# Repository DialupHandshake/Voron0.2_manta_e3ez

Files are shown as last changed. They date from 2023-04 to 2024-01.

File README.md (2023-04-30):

# Voron0.2_manta_e3ez
Configuration for Voron 0.2 printer with Bigtreetech Manta E3EZ board and CB1.
If you just need a config with pin mapping for Voron 0, grab btt_manta_e3ez_voron0_generic.cfg and rename it to printer.cfg. 
Otherwise feel free to use my printer.cfg.
If you are using CAN bus, there is a config for that in the CAN_bus_config folder.

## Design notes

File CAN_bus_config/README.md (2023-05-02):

This is a config with Manta E3EZ and BTT EBB36 communicating on CAN network, without KAMP (Klipper Adaptive Meshing and Purging) installed.

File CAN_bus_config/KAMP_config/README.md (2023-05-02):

This is a config with Manta E3EZ with EBB36 communicating over CAN, with KAMP (Klipper Adaptive Meshing and Purging) installed but used only for purging.

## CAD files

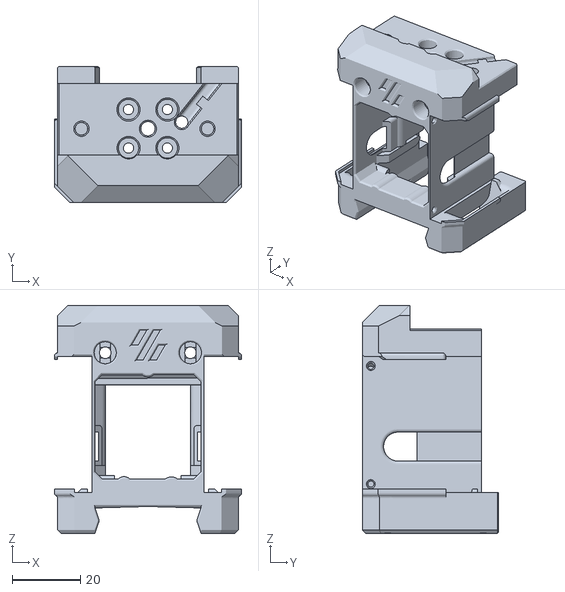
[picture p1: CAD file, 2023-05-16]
dragonburner.stl
55.0 x 40.0 x 66.9

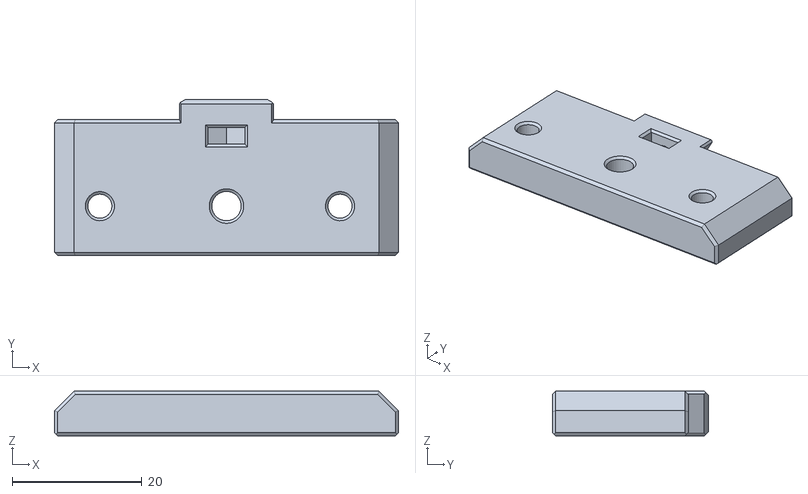
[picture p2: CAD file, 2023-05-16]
Orbiter_mount.stl
53.0 x 24.1 x 6.90

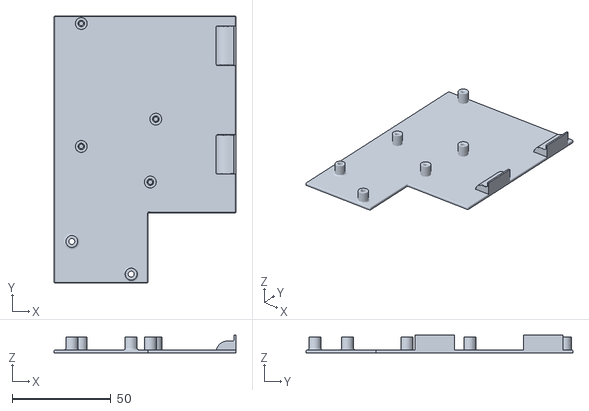
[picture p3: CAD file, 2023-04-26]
Board_tray_buck.stl
92.0 x 135.0 x 9.00

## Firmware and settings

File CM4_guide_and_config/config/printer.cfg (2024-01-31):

# This file contains common pin mappings for the BIGTREETECH Manta E3EZ and BIGTREETECH EBB36 v1.2 running on CAN network.
# To use this config, compile the firmware with the following options:
# Micro-controller Architecture (STMicroelectronics STM32) -- borth boards
# Processor model (STM32G0B1) -- borth boards (EBB36 v1.1 and 1.2 use STM32G0B1, and EBB36 v1.0 uses STM32F072. More details here: https://github.com/maz0r/klipper_canbus/blob/main/index.md)
# Clock Reference (8 MHz crystal) -- both boards
# Application start offset (8KiB offset) -- both boards
# (1000000) CAN bus speed -- both boards
# When building for Manta E3EZ, select "USB to CAN bus bridge on PA11/PA12" and "CAN bus (on PB12/PB13)"
# When building for EBB36 v1.2, select "CAN bus (on PB0/PB1)"



[include mainsail.cfg]
[include KAMP_Settings.cfg]
[include pid_macro.cfg]

# Enable object exclusion
[exclude_object]

[force_move]
enable_force_move: True

[respond]

[skew_correction]

# Enable arcs support
[gcode_arcs]
resolution: 0.1

[virtual_sdcard]
path: ~/printer_data/gcodes
on_error_gcode: CANCEL_PRINT

[mcu]
canbus_uuid=2cca93642053

[mcu can0]
canbus_uuid=84c9eddddf6b							# Run the following command to locate the uuid >   ~/klippy-env/bin/python ~/klipper/scripts/canbus_query.py can0

#####################################################################
#     	Printer definition
#####################################################################

[printer]
kinematics: corexy
max_velocity: 300
max_accel: 2000
max_z_velocity: 15
max_z_accel: 45
square_corner_velocity: 6.0

#####################################################################
#     	 X/Y Stepper Settings
#####################################################################

[stepper_x]
step_pin: PA14
dir_pin: PA10
enable_pin: !PA13
microsteps: 32
#full_steps_per_rotation: 200
rotation_distance: 40
endstop_pin: tmc2209_stepper_x:virtual_endstop
position_endstop: 120
position_max: 120
homing_speed: 40								 	# For sensorless homing it is recommended not to go above 40mm/s  
homing_retract_dist: 0

[tmc2209 stepper_x]
uart_pin: PB8
diag_pin: PC4										# Sensorless homing won't work if this pin is not jumped
interpolate: False									
run_current: 0.5
sense_resistor: 0.110
stealthchop_threshold: 0						# Set to 999999 to turn stealthchop on, and 0 to use spreadcycle
driver_SGTHRS: 60          							# Sensitivity for sensorless homing, max sensitivity is 255

[stepper_y]
step_pin: PC8
dir_pin: PA15
enable_pin: !PC14
microsteps: 32
rotation_distance: 40
endstop_pin: tmc2209_stepper_y:virtual_endstop
position_endstop: 120
position_max: 120
homing_speed: 40
homing_retract_dist: 0

[tmc2209 stepper_y]
uart_pin: PC9
diag_pin: PB0										# Sensorless homing won't work if this pin is not jumped
interpolate: False									
run_current: 0.5
sense_resistor: 0.110
stealthchop_threshold: 0					# Set to 999999 to turn stealthchop on, and 0 to use spreadcycle
driver_SGTHRS: 100            						# Sensitivity for sensorless homing, max sensitivity is 255

#####################################################################
#   Z Stepper Settings
#####################################################################

[stepper_z]
step_pin: PD2
dir_pin: PD4
enable_pin: !PD3
microsteps: 32
rotation_distance: 8
endstop_pin: probe:z_virtual_endstop
#position_endstop: 120
position_max: 120
position_min: -6
homing_speed: 20
second_homing_speed: 3.0
homing_retract_dist: 3.0

[tmc2209 stepper_z]
uart_pin: PD0
#diag_pin: PC6
interpolate: False
run_current: 0.3				
sense_resistor: 0.110
stealthchop_threshold: 0

#####################################################################
#   Extruder
#####################################################################

[extruder]
step_pin: can0:EXT_STEP
dir_pin: can0:EXT_DIR
enable_pin: !can0:EXT_EN
rotation_distance: 35.486
gear_ratio: 75:10 										#For Orbiter 2.0
microsteps: 16
full_steps_per_rotation: 200 							#1.8deg Motor
max_extrude_only_distance: 500
max_extrude_only_velocity: 120
max_extrude_only_accel: 1500
max_extrude_cross_section: 5
nozzle_diameter: 0.400
filament_diameter: 1.750
heater_pin: can0:HE0
sensor_pin: can0:TH0
sensor_type: EPCOS 100K B57560G104F  
#control: pid
min_temp: 0
max_temp: 300
min_extrude_temp: 170
#pid_Kp: 21.527
#pid_Ki: 1.063
#pid_Kd: 108.982

[tmc2209 extruder]
uart_pin: can0:EXT_UART
interpolate: True
stealthchop_threshold: 0
run_current: 0.5
sense_resistor: 0.110
driver_TBL: 0
driver_HEND: 6
driver_HSTRT: 7
driver_TOFF: 4

#####################################################################
#   Bed Heater
#####################################################################

[heater_bed]
heater_pin: PB2 #HB
sensor_type: EPCOS 100K B57560G104F 					#Generic 3950
sensor_pin: PA3 #TB
smooth_time: 3.0
#max_power: 0.6                           				# Only needed for 100w pads
min_temp: 0
max_temp: 120
#control: pid                                        	# Do PID calibration after initial checks
#pid_kp: 68.453
#pid_ki: 2.749
#pid_kd: 426.122

#####################################################################
#   Bed Leveling
#####################################################################

[bed_mesh]
speed: 200
horizontal_move_z: 25
mesh_min: 25,25
mesh_max: 95, 95
zero_reference_position: 60, 60
probe_count: 3,3
algorithm: bicubic

[probe]
pin: can0:PROBE_2
x_offset: 20
y_offset: 0
#z_offset: 10
speed: 20.0
samples: 2
sample_retract_dist: 5.0
lift_speed: 30.0
samples_tolerance: 0.01
samples_tolerance_retries: 15
deactivate_on_each_sample: 0

[homing_override]
axes: z
gcode:
    SET_KINEMATIC_POSITION Z=0
    G1 Z5
    G28 X Y
    Query_Probe
    SS_CONDITIONAL_TAKE_PROBE
    G1 X40 Y110
    G28 Z
    G91
    G1 Z1
    G90
    SS_STOW_PROBE
	
[servo probeServo]
pin: PA7
minimum_pulse_width: 0.000544


#############################################################################################################################################
#   Firmware retraction -- uncomment this section and enable firmware retraction in slicer to use firmware retraction
#############################################################################################################################################

[firmware_retraction]
retract_length: 1.2
#   The length of filament (in mm) to retract when G10 is activated,
#   and to unretract when G11 is activated (but see
#   unretract_extra_length below). The default is 0 mm.
retract_speed: 120
#   The speed of retraction, in mm/s. The default is 20 mm/s.
unretract_extra_length: 0
#   The length (in mm) of *additional* filament to add when
#   unretracting.
unretract_speed: 90
#   The speed of unretraction, in mm/s. The default is 10 mm/s.

#####################################################################
#     	Temperature Sensors
#####################################################################

[temperature_sensor MCU]
sensor_type: temperature_mcu
min_temp: 0
max_temp: 100

[temperature_sensor CM4 Host]
sensor_type: temperature_host
min_temp: 10
max_temp: 100

[temperature_sensor EBB36 CAN Board]
sensor_type: temperature_mcu
sensor_mcu: can0

[temperature_sensor Chamber]
sensor_type: Generic 3950 
sensor_pin: PA4
min_temp: 0
max_temp: 100

## PT100 for EBB boards with MAX31865 chip
# [temperature_sensor PT100]
# sensor_type: MAX31865
# sensor_pin: can0:PT100_CS
# spi_bus: spi1
# min_temp: -50
# max_temp: 350
# rtd_reference_r: 430

#####################################################################
#   Fans
#####################################################################

# Hot End fan
[heater_fan hotend_fan]
pin: can0:FAN1
max_power: 1.0
kick_start_time: 0.5
heater: extruder
heater_temp: 50.0

# Part Cooling fan
[fan]
pin: can0:FAN0
kick_start_time: 0.25
cycle_time: 0.15
off_below: 0.10

# Mainboard fan
[heater_fan controller_fan]
pin: PB14

#####################################################################
#   Board Pins
#####################################################################

[board_pins]
aliases:
    # EXP1 header
    EXP1_1=PC1, EXP1_3=PC3, EXP1_5=PC0, EXP1_7=PA2, EXP1_9=<GND>,
    EXP1_2=PC2,  EXP1_4=<RST>, EXP1_6=PA0, EXP1_8=PA1, EXP1_10=<5V>
	
[board_pins EBB36_G0B1_v1.2] 
mcu: can0
aliases:
aliases_step:
    EXT_EN=PD2,EXT_STEP=PD0,EXT_DIR=PD1,EXT_UART=PA15
aliases_limitsw: # these are preferred for endstops (including klicky)
    LIMIT_1=PB7,LIMIT_2=PB5,LIMIT_3=PB6
aliases_bltouch: # these are the dupont connectors for bltouch
    PROBE_1=PB9,PROBE_2=PB8
aliases_fans:
    FAN0=PA0,FAN1=PA1
aliases_thermistors:
    TH0=PA3,PT100_CS=PA4,PT100_SCLK=PA5,PT100_MISO=PA6,PT100_MOSI=PA7
aliases_heaters:
    HE0=PB13
aliases_rgb:
    RGBLED=PD3
aliases_adxl:
    ADXL_CS=PB12,ADXL_SCLK=PB10,ADXL_MISO=PB2,ADXL_MOSI=PB11
aliases_i2c:
    AUX0=PB3,AUX1=PB4

#[output_pin PS_ON]
#pin: PA9

#[output_pin pb9_pin]
#pin: PB9

#[neopixel my_neopixel]
#pin: PC7
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

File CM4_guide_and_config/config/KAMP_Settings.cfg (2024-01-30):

# Below you can include specific configuration files depending on what you want KAMP to do:

# [include ./KAMP/Adaptive_Meshing.cfg]       # Include to enable adaptive meshing configuration.
[include ./KAMP/Line_Purge.cfg]             # Include to enable adaptive line purging configuration.
# [include ./KAMP/Voron_Purge.cfg]            # Include to enable adaptive Voron logo purging configuration.
[include ./KAMP/Smart_Park.cfg]             # Include to enable the Smart Park function, which parks the printhead near the print area for final heating.

[gcode_macro _KAMP_Settings]
description: This macro contains all adjustable settings for KAMP 

# The following variables are settings for KAMP as a whole.
variable_verbose_enable: True               # Set to True to enable KAMP information output when running. This is useful for debugging.

# The following variables are for adjusting adaptive mesh settings for KAMP.
variable_mesh_margin: 0                     # Expands the mesh size in millimeters if desired. Leave at 0 to disable.
variable_fuzz_amount: 0                     # Slightly randomizes mesh points to spread out wear from nozzle-based probes. Leave at 0 to disable.

# The following variables are for those with a dockable probe like Klicky, Euclid, etc.                 # ----------------  Attach Macro | Detach Macro
variable_probe_dock_enable: True           # Set to True to enable the usage of a dockable probe.      # ---------------------------------------------
variable_attach_macro: 'SS_CONDITIONAL_TAKE_PROBE'       # The macro that is used to attach the probe.               # Klicky Probe:   'Attach_Probe' | 'Dock_Probe'
variable_detach_macro: 'SS_CONDITIONAL_STOW_PROBE'         # The macro that is used to store the probe.                # Euclid Probe:   'Deploy_Probe' | 'Stow_Probe'
                                                                                                        # Legacy Gcode:   'M401'         | 'M402'

# The following variables are for adjusting adaptive purge settings for KAMP.
variable_purge_height: 0.6                  # Z position of nozzle during purge, default is 0.8.
variable_tip_distance: -7                    # Distance between tip of filament and nozzle before purge. Should be similar to PRINT_END final retract amount.
variable_purge_margin: 10                   # Distance the purge will be in front of the print area, default is 10.
variable_purge_amount: 40                   # Amount of filament to be purged prior to printing.
variable_flow_rate: 12                      # Flow rate of purge in mm3/s. Default is 12.

# The following variables are for adjusting the Smart Park feature for KAMP, which will park the printhead near the print area at a specified height.
variable_smart_park_height: 10              # Z position for Smart Park, default is 10.

gcode: # Gcode section left intentionally blank. Do not disturb.

    {action_respond_info(" Running the KAMP_Settings macro does nothing, it is only used for storing KAMP settings. ")}

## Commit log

2023-03-20 Initial file upload
    Going to use these files to Frankenstein a working Voron 0.2 configuration.
    [btt_manta_m4p.cfg, generic_btt_manta_e3ez_config.cfg, printer.cfg]
2023-03-20 Update printer.cfg
    Not ready for use yet
    [printer.cfg]
2023-03-22 printer.cfg now includes mainsail.cfg
    [mainsail.cfg, printer.cfg]
2023-03-22 Update printer.cfg
    Fixed stepper direction
    [printer.cfg]
2023-03-23 Macros
    Added macros to printer.cfg and added macros.cfg, which contains example macros
    [macros.cfg, printer.cfg]
2023-03-23 Update printer.cfg
    Adjusted macros
    [printer.cfg]
2023-04-20 CAN BUS setup
    [ebb36.cfg, mainsail.cfg, printer.cfg]
2023-04-20 Consolidating into one cfg file
    [ebb36.cfg, printer_consolidated.cfg]
2023-04-20 Changed sensor type
    [ebb36.cfg]
2023-04-20 Updated BLTouch pins
    [printer_consolidated.cfg]
2023-04-26 Mainboard bracket with buck converter
    [Board_tray_buck.stl]
2023-05-01 Added configs with KAMP
    [Adaptive_Mesh.cfg, Line_Purge.cfg, Simplify3D_Fix.cfg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]
2023-05-03 Switched from stealthchop to spreadcycle
    Switching from stealthchop to spreadcycle fixed an issue where printer made a loud noise when moving diagonally.
    [printer.cfg]
2023-05-09 Added SlideSwipe configs
    [Adaptive_Mesh.cfg, Line_Purge.cfg, Simplify3D_Fix.cfg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]
2023-05-16 Added custom stl files
    [Orbiter_mount.stl, dragonburner.stl]
2023-12-19 Working CM4 configs
    Added working configs with CM4.
    [Adaptive_Mesh.cfg, Line_Purge.cfg, Simplify3D_Fix.cfg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]
2023-12-19 Updated print_end
    [printer.cfg]
2024-01-30 Updated config files
    Files are for Voron 0 with Slideswipe, CAN, and KAMP
    [Adaptive_Mesh.cfg, Adaptive_Meshing.cfg, KAMP_Settings.cfg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]
2024-01-31 firmware retraction
    [printer.cfg]
